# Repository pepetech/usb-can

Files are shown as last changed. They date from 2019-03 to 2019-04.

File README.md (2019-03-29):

# usb-can

This is an open source C++ library for use with the <a href="https://media.giphy.com/media/J0WeVOLjuqW2I/giphy.gif">USB-CAN</a> converter developed by Rafael Silva and João Silva

## Getting Started

These instructions will get you a copy of the project up and running on your local machine for development and testing purposes.

### Prerequisites

- You will need root access to a Linux machine.
- You will need to install development packages for libudev and libusb

- You will need the <a href="https://github.com/signal11/hidapi">hidapi</a> library installed 

- You will need to install libusb
```
sudo apt-get install libudev-dev libusb-1.0-0-dev
```

### Installing

A step by step series of examples that tell you how to get a development environment running

- Clone this repository to your working directory

```
sudo git clone https://github.com/Crying-Face-Emoji/MCP2210-CAN-sdk
```

- Go to the source directory

```
cd MCP2210-CAN-sdk/
```

- Run make

```
sudo make
```

## Running

- You may need to add the provided udev rules to the /etc/udev/rules.d directory.

```
sudo cp mcp2210-hid.rules /etc/udev/rules.d
```
- Depending on your user permissions, you might need to run the compilled binary with root access (sudo)

TODO: Explain how to run the automated tests for this system

## Authors

* **Rafael Silva** - *Initial work* - [crying-face-emoji](https://github.com/crying-face-emoji)
* **João Silva** - *Initial work* - [vankxr](https://github.com/vankxr)

See also the list of [contributors](https://github.com/Crying-Face-Emoji/MCP2210-CAN-sdk/graphs/contributors) who participated in this project.

## License

This project is licensed under the GNU General Public License v3.0 - see the [LICENSE.md](LICENSE.md) file for details

## Acknowledgments

* <a href="https://github.com/kerrydwong/MCP2210-Library">kerrydwong</a> - *mcp2210 library used as base*
* <a href="https://github.com/signal11/hidapi">signal11</a> - *original HID API*

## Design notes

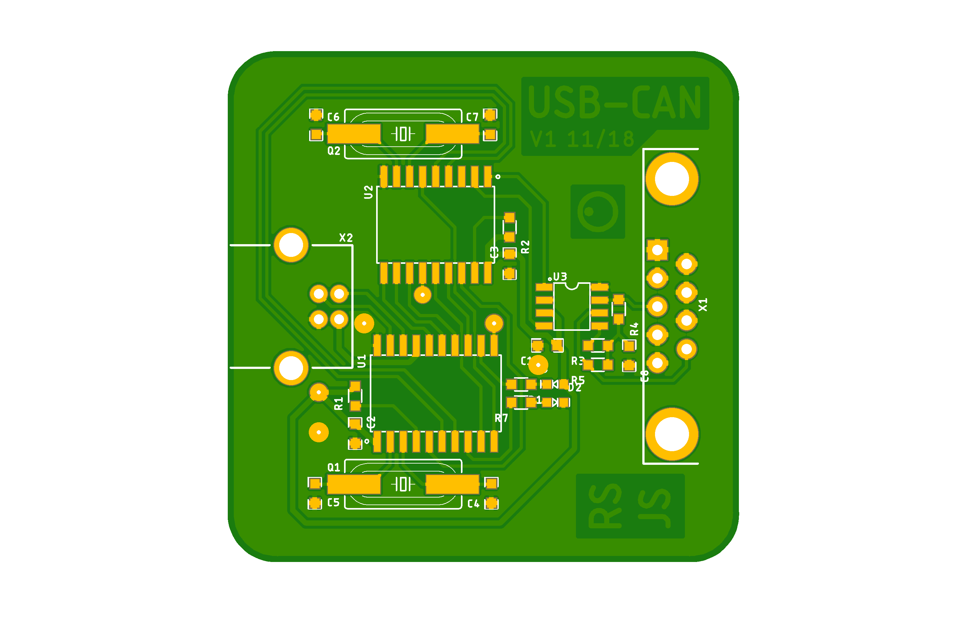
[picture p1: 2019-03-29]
hardware/hv0a/usb-can.png

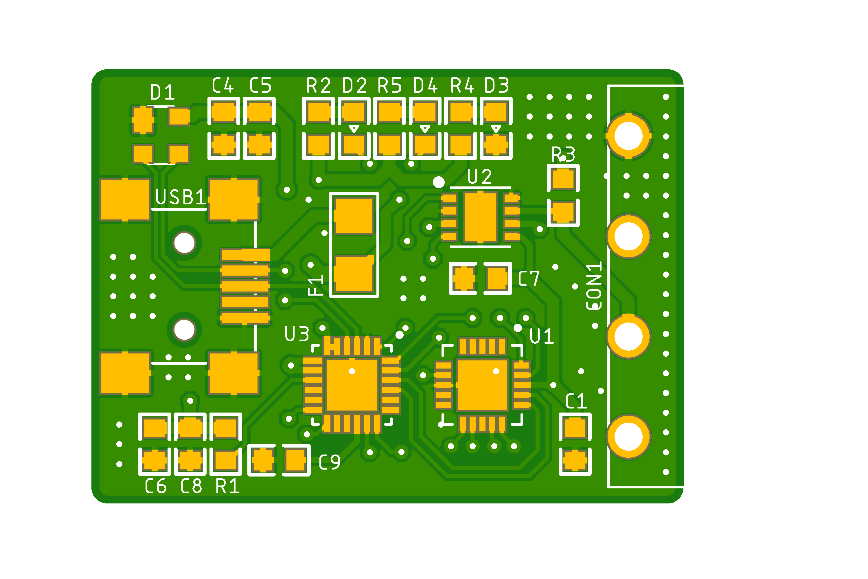
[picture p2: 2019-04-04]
hardware/hv1a/usb-can-top.png

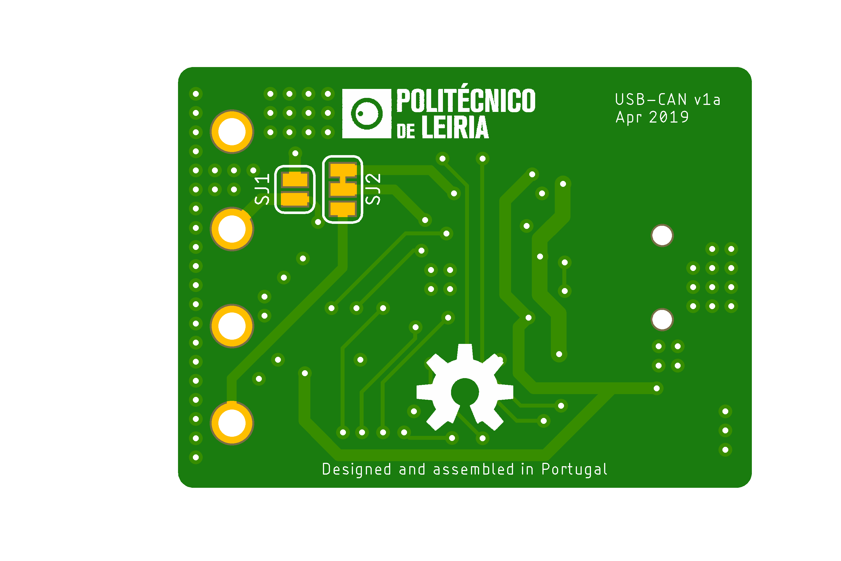
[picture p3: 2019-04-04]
hardware/hv1a/usb-can-bot.png

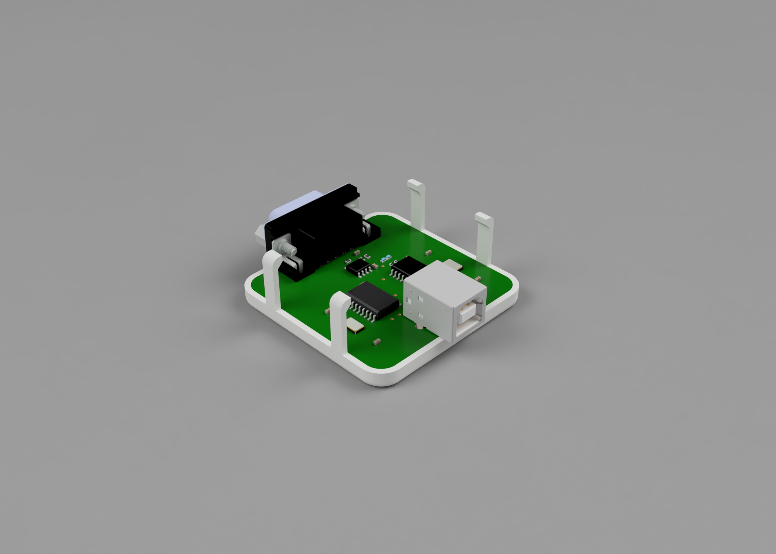
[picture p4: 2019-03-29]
cad/hv0a/asm_2018-Nov-21_03-18-42AM-000_CustomizedView5582314474.png

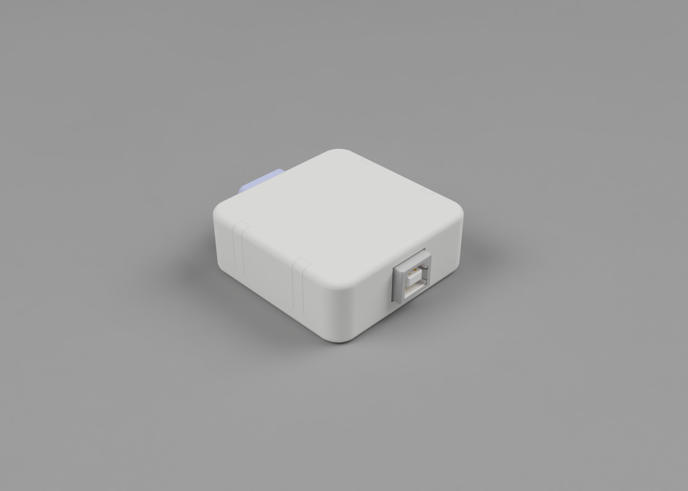
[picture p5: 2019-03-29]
cad/hv0a/asm_2018-Nov-21_03-18-42AM-000_CustomizedView5582314472.png

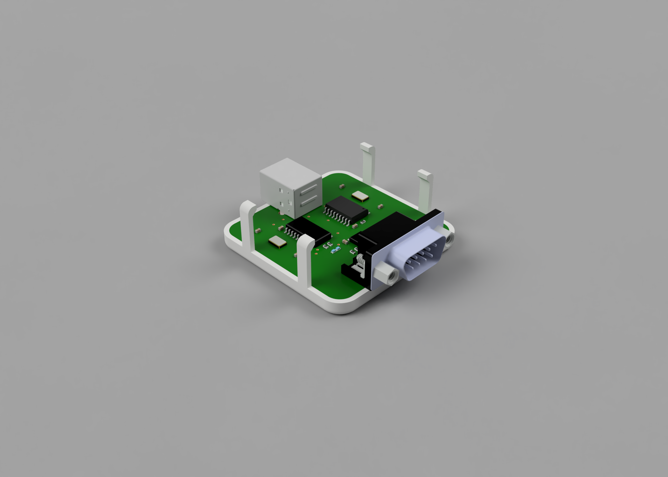
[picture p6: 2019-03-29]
cad/hv0a/asm_2018-Nov-21_03-19-44AM-000_CustomizedView13928471128.png

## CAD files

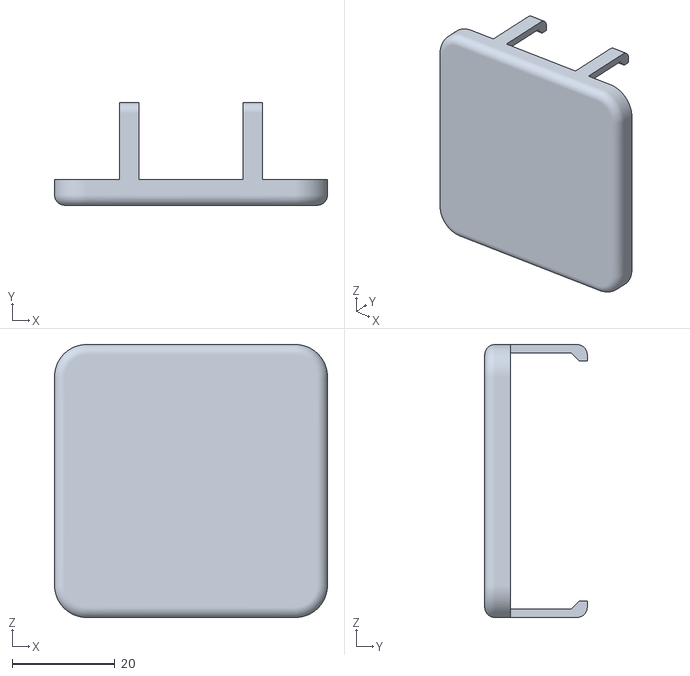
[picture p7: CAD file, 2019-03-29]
cad/hv0a/Bot.stl
53.2 x 20.0 x 53.2

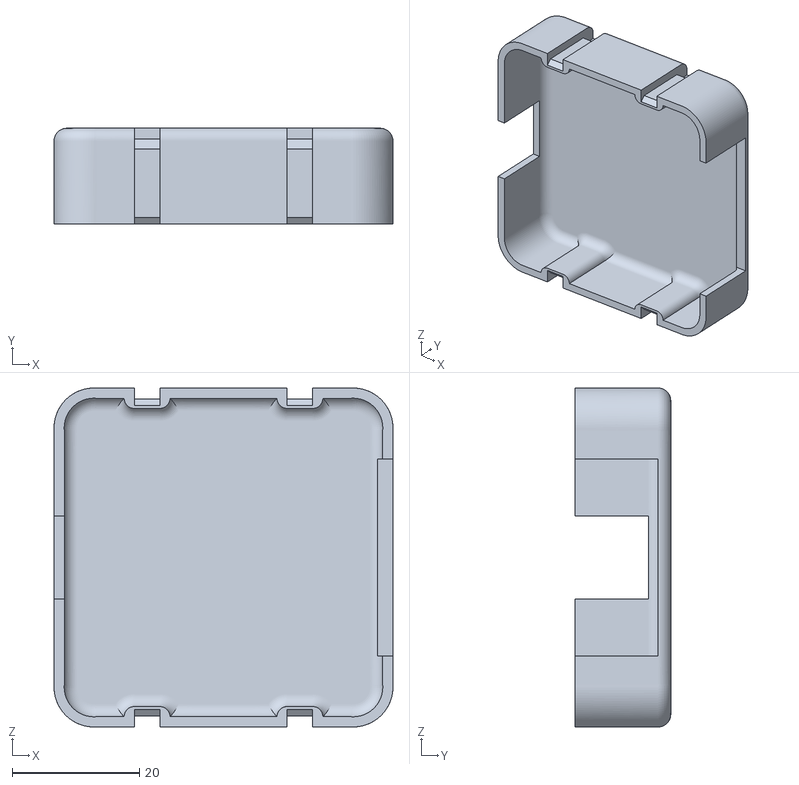
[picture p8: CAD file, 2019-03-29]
cad/hv0a/Top.stl
53.2 x 15.0 x 53.2

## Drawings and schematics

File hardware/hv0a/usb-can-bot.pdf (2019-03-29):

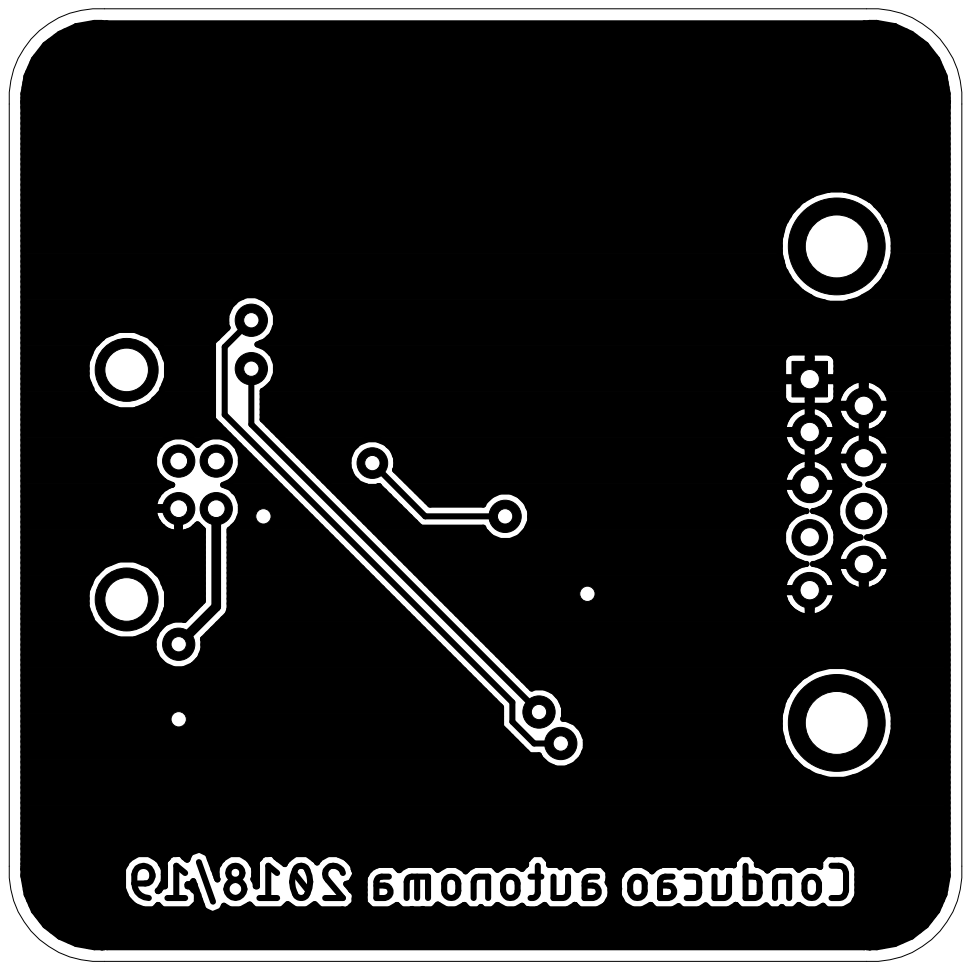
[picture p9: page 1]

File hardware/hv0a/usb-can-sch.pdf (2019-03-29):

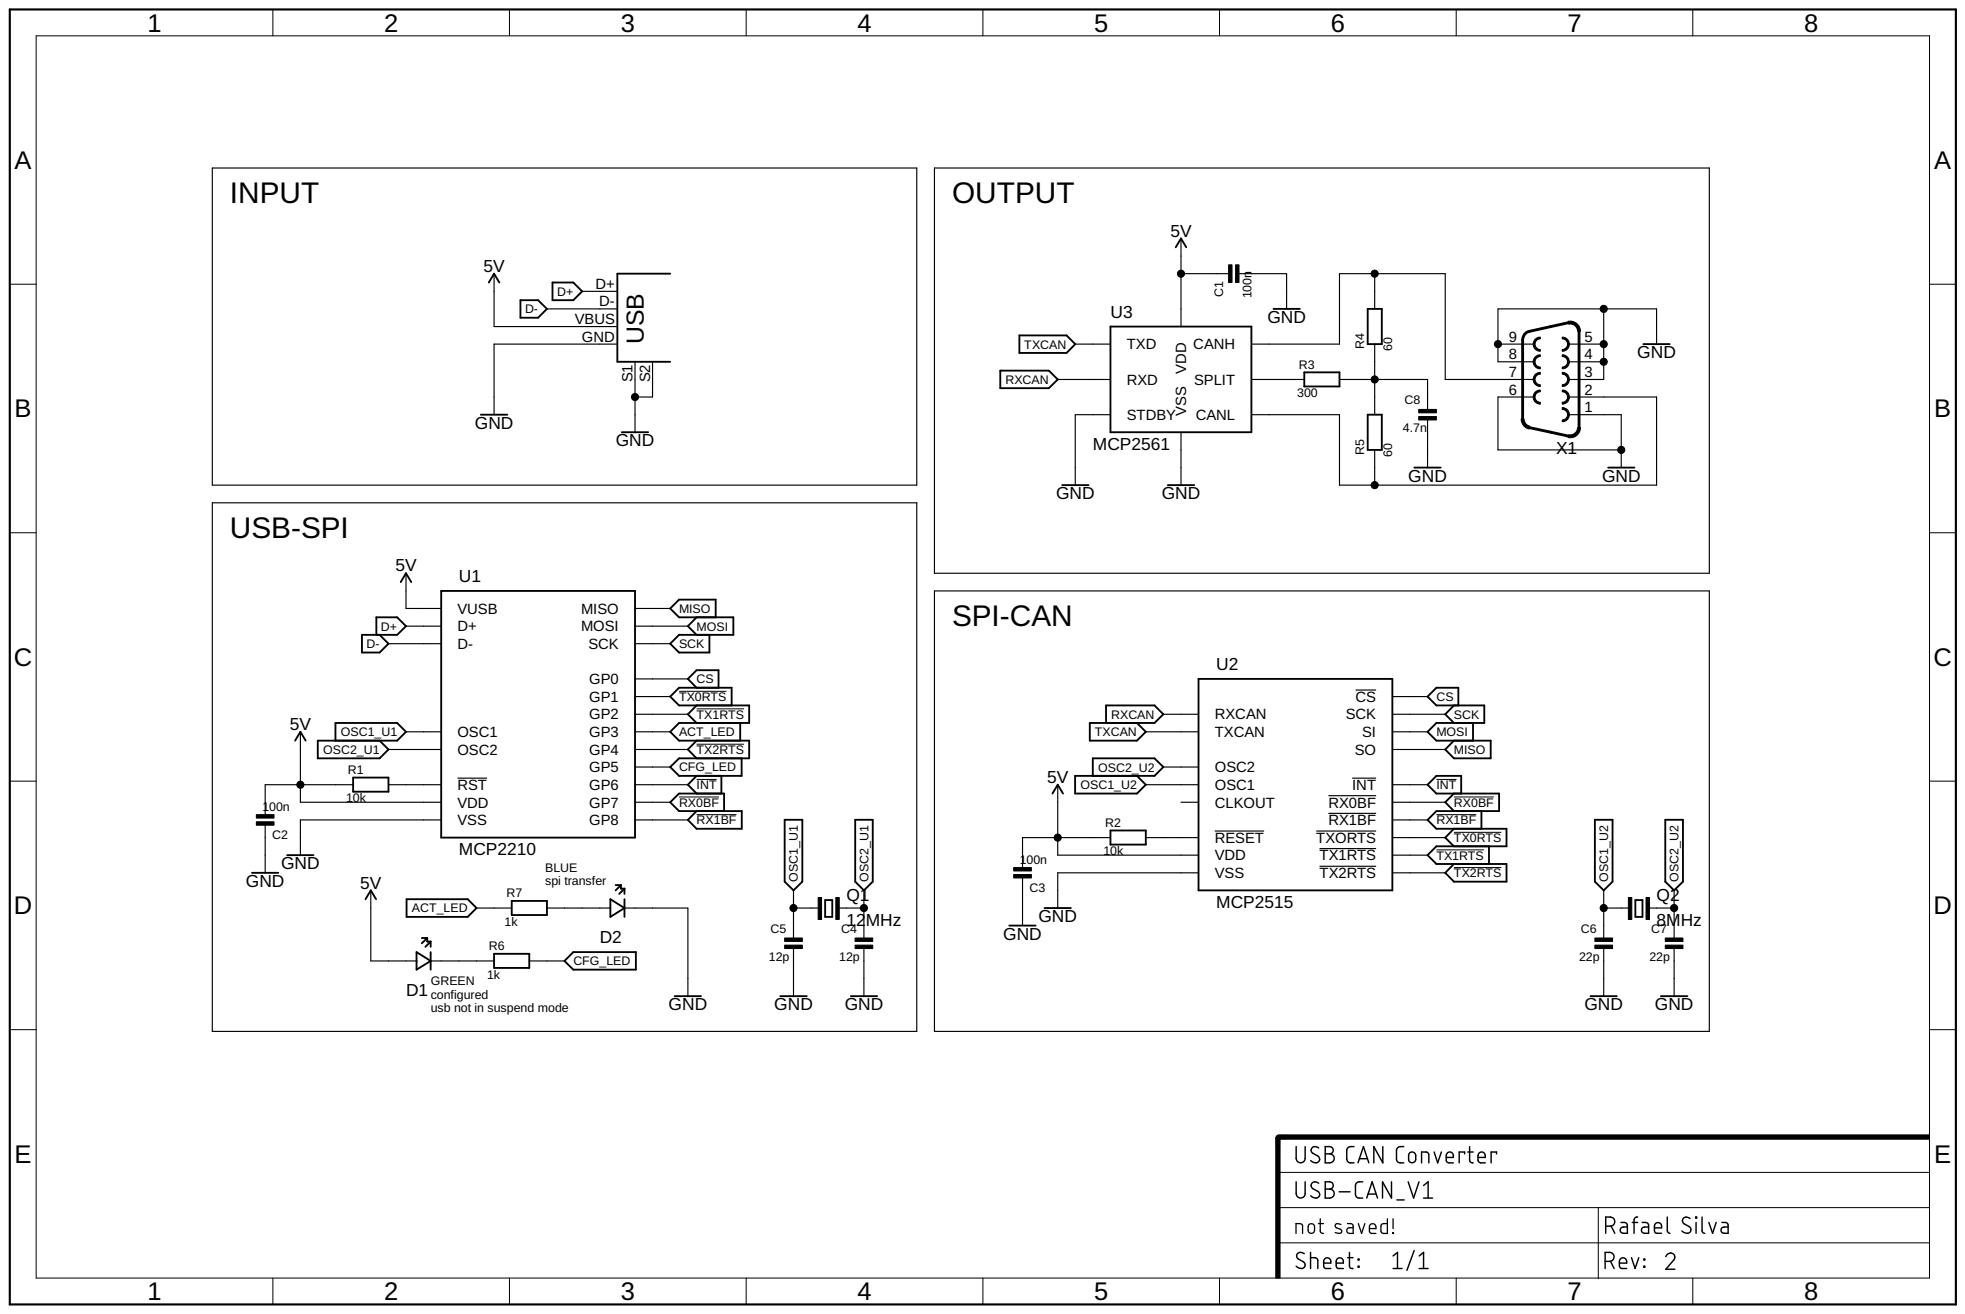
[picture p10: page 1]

GREEN
configured
usb not in suspend mode

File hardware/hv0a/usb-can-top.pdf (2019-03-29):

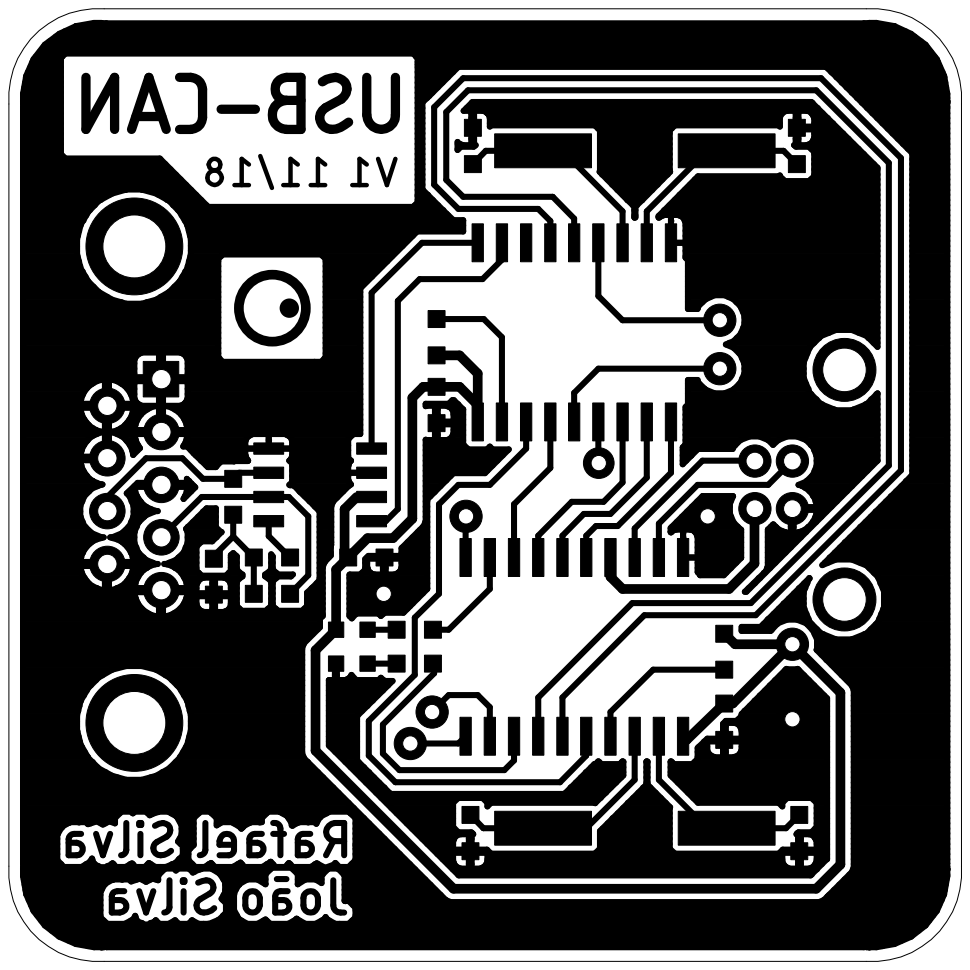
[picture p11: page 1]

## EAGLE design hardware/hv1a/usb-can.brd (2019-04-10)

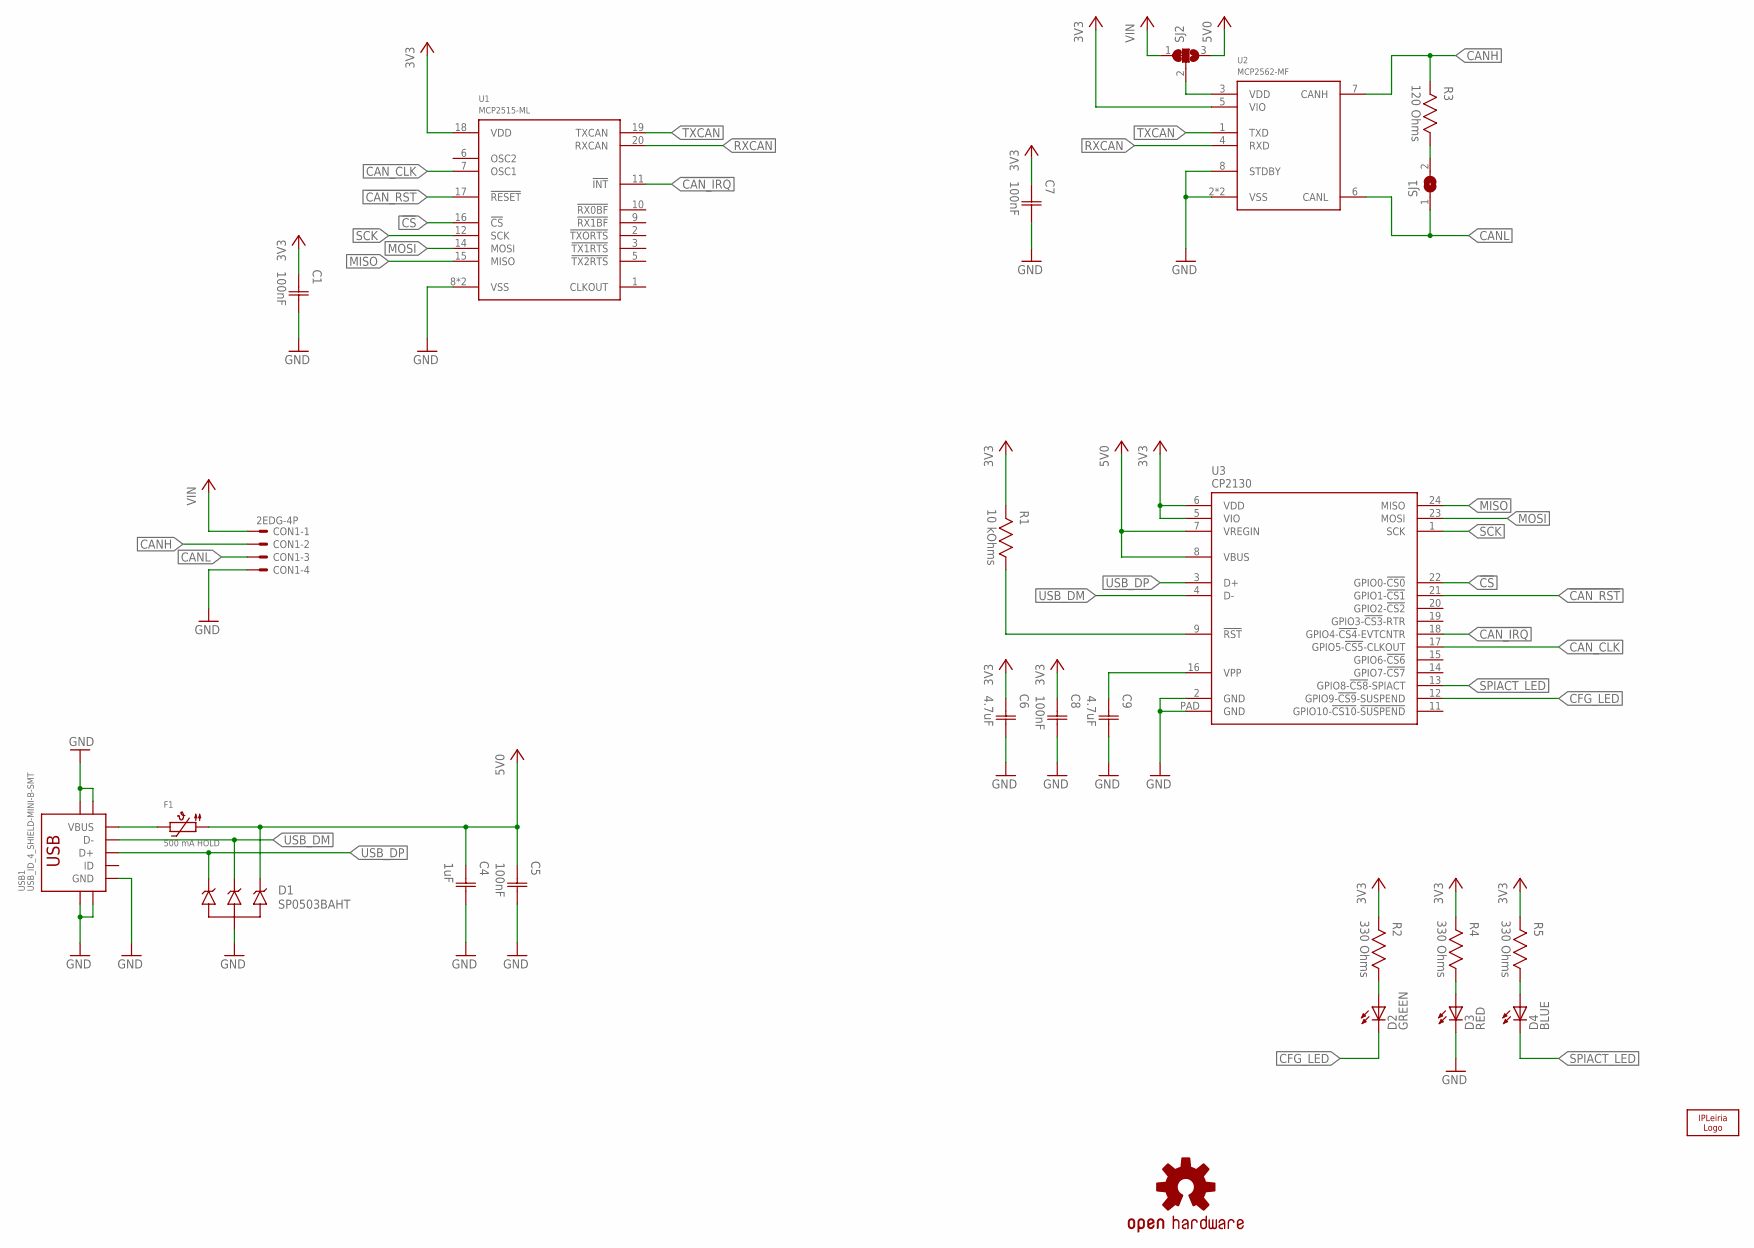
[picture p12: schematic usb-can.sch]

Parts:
C1, C5, C7, C8: 100nF; CAP0603
C4: 1uF; CAP0603
C6, C9: 4.7uF; CAP0603
CON1: 2EDG-4P
D1: SP0503BAHT; SOT143
D2: GREEN; 0603
D3: RED; 0603
D4: BLUE; 0603
F1: 500 mA HOLD; 1206
LOGO1: IPL-10MM; IPL_10MM
LOGO2: OSHW-LOGOM; OSHW-LOGO-M
R1: 10 kOhms; RES0603
R2, R4, R5: 330 Ohms; RES0603
R3: 120 Ohms; RES0603
SJ1: SJS; SJ_S
SJ2: SJ2CS; SJ2C_S
U1: MCP2515-ML; QFN20
U2: MCP2562-MF; DFN8
U3: CP2130; QFN24
USB1: USB_ID_4_SHIELD-MINI-B-SMT; USB-MB-S

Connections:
3V3: C1.1 (C1), C6.1 (C1), C7.1 (C1), C8.1 (C1), R1.2, R2.2, R4.2, R5.2, U1.18 (VDD), U2.5 (VIO), U3.5 (VIO), U3.6 (VDD)
5V0: C4.1 (C1), C5.1 (C1), D1.4, F1.1, SJ2.3, U3.7 (VREGIN), U3.8 (VBUS)
!CAN_IRQ: U1.11 (!INT!), U3.18 (GPIO4-!CS4!-EVTCNTR)
!CAN_RST: U1.17 (!RESET!), U3.21 (GPIO1-!CS1)
!CS: U1.16 (!CS!), U3.22 (GPIO0-!CS0)
CANH: CON1.P$2, R3.2, U2.7 (CANH)
CANL: CON1.P$3, SJ1.1, U2.6 (CANL)
CAN_CLK: U1.7 (OSC1), U3.17 (GPIO5-!CS5!-CLKOUT)
CFG_LED: D2.1 (C), U3.12 (GPIO9-!CS9!-SUSPEND)
GND: C1.2 (C2), C4.2 (C2), C5.2 (C2), C6.2 (C2), C7.2 (C2), C8.2 (C2), C9.2 (C2), CON1.P$4, D1.1, D3.1 (C), U1.8 (VSS), U1.PAD (VSS), U2.2 (VSS), U2.8 (STDBY), U2.9 (VSS), U3.2 (GND), U3.PAD (GND), USB1.GND, USB1.GND1 (SHIELD), USB1.GND2 (SHIELD), USB1.GND3 (SHIELD), USB1.GND4 (SHIELD)
MISO: U1.15 (MISO), U3.24 (MISO)
MOSI: U1.14 (MOSI), U3.23 (MOSI)
unnamed: SJ2.2, U2.3 (VDD)
unnamed: R3.1, SJ1.2
unnamed: C9.1 (C1), U3.16 (VPP)
unnamed: R1.1, U3.9 (!RST)
unnamed: F1.2, USB1.VBUS
unnamed: D3.2 (A), R4.1
unnamed: D4.2 (A), R5.1
unnamed: D2.2 (A), R2.1
RXCAN: U1.20 (RXCAN), U2.4 (RXD)
SCK: U1.12 (SCK), U3.1 (SCK)
SPIACT_LED: D4.1 (C), U3.13 (GPIO8-!CS8!-SPIACT)
TXCAN: U1.19 (TXCAN), U2.1 (TXD)
USB_DM: D1.3, U3.4 (D-), USB1.D-
USB_DP: D1.2, U3.3 (D+), USB1.D+
VIN: CON1.P$1, SJ2.1

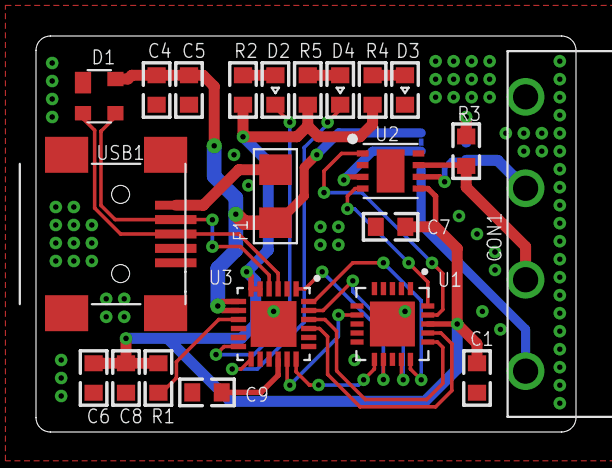
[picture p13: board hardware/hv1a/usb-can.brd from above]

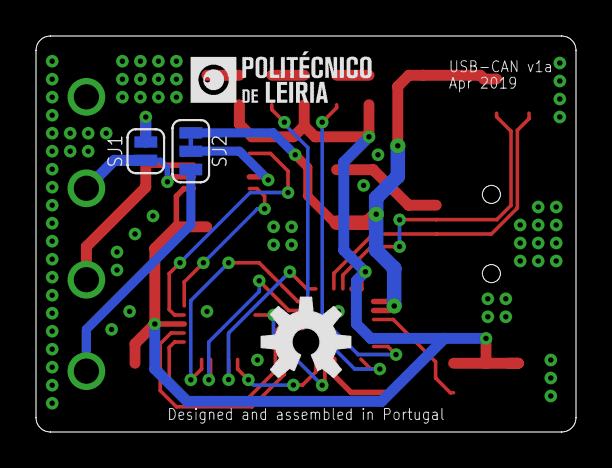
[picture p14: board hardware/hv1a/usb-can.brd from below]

Board: 2 copper layers, 30.0 x 22.0 mm, 26 parts (4 on the bottom side), 27 nets.

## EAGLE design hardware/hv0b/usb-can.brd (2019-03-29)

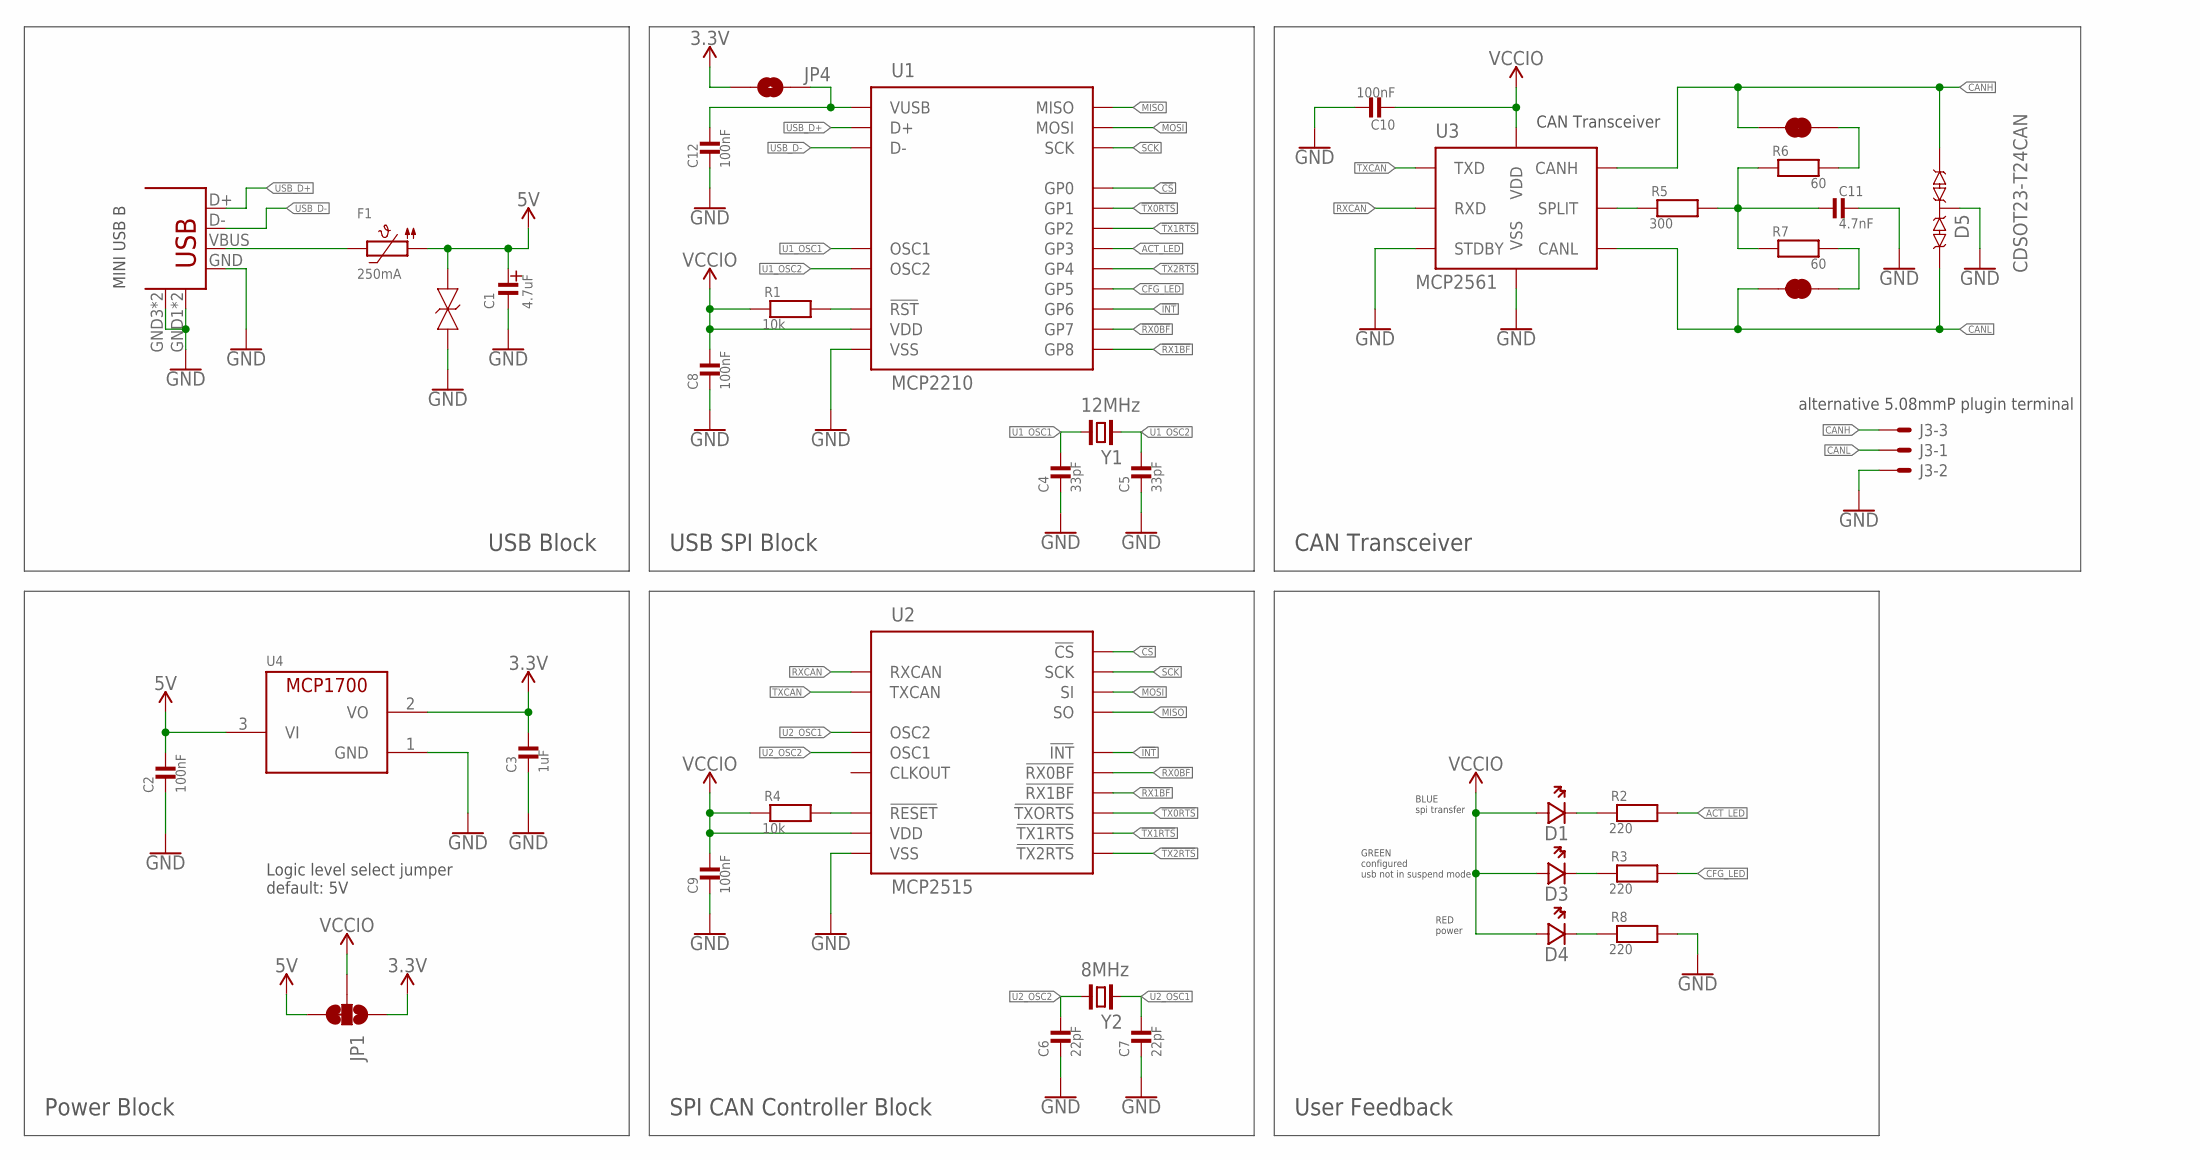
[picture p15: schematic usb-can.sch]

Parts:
C1: 4.7uF; EIA3216
C2, C8, C9, C10, C12: 100nF; 0603_WAVE
C3: 1uF; 0603_WAVE
C4, C5: 33pF; 0603_WAVE
C6, C7: 22pF; 0603_WAVE
C11: 4.7nF; 0603_WAVE
D1: Blue; CHIPLED_0603
D2: PESD5V0S1BAF; SOD323
D3: Green; CHIPLED_0603
D4: Red; CHIPLED_0603
D5: CDSOT23-T24CAN; SOT-23-3
F1: 250mA; _1206
J2: USB_MINI_BMINIB; USB-MINIB
J3: 1X32EHGR; 2EHGR
JP1: JUMPER-SMT_3_1-NC_TRACE_SILK; SMT-JUMPER_3_1-NC_TRACE_SILK
JP2, JP3: JUMPER-SMT_2_NC_TRACE_SILK; SMT-JUMPER_2_NC_TRACE_SILK
JP4: JUMPER-SMT_2_NO_SILK; SMT-JUMPER_2_NO_SILK
R1, R4: 10k; 0603_WAVE
R2, R3, R8: 220; 0603_WAVE
R5: 300; 0603_WAVE
R6, R7: 60; 0603_WAVE
U1: MCP2210; SOIC-20_300MIL
U2: MCP2515; SOIC-18_300MIL
U3: MCP2561; SOIC_8
U4: 250mA; SOT-23
Y1: 12MHz; 2-SMD-5X3
Y2: 8MHz; 2-SMD-5X3

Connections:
3.3V: C3.P$1, JP1.1, JP4.2, U4.2 (VO)
5V: C1.+ (AN), C2.P$1, D2.P$1, F1.1, JP1.3, U4.3 (VI)
!CS: U1.P$5 (GP0), U2.P$16 (!CS!)
!INT: U1.P$14 (GP6), U2.P$12 (!INT!)
!RX0BF: U1.P$15 (GP7), U2.P$11 (!RX0BF!)
!RX1BF: U1.P$16 (GP8), U2.P$10 (!RX1BF!)
!TX0RTS: U1.P$6 (GP1), U2.P$4 (!TXORTS!)
!TX1RTS: U1.P$7 (GP2), U2.P$5 (!TX1RTS!)
!TX2RTS: U1.P$10 (GP4), U2.P$6 (!TX2RTS!)
ACT_LED: R2.P$2, U1.P$8 (GP3)
CANH: D5.P$2 (2), J3.P$3, JP3.2, U3.P$7 (CANH)
CANL: D5.P$1 (1), J3.P$1, JP2.2, U3.P$6 (CANL)
CFG_LED: R3.P$2, U1.P$12 (GP5)
GND: C1.- (CA), C2.P$2, C3.P$2, C4.P$2, C5.P$2, C6.P$2, C7.P$2, C8.P$2, C9.P$2, C10.P$1, C11.P$1, C12.P$2, D2.P$2, D5.P$3 (3), J2.GND, J2.GND1, J2.GND2, J2.GND3, J2.GND4, J3.P$2, R8.P$2, U1.P$20 (VSS), U2.P$9 (VSS), U3.P$2 (VSS), U3.P$8 (STDBY), U4.1 (GND)
MISO: U1.P$13 (MISO), U2.P$15 (SO)
MOSI: U1.P$9 (MOSI), U2.P$14 (SI)
unnamed: JP2.1, R7.P$2
unnamed: D1.C (CA), R2.P$1
unnamed: D3.C (CA), R3.P$1
unnamed: R1.P$2, U1.P$4 (!RST!)
unnamed: R4.P$2, U2.P$17 (!RESET!)
unnamed: D4.C (CA), R8.P$1
unnamed: JP3.1, R6.P$2
unnamed: F1.2, J2.VBUS
unnamed: C12.P$1, JP4.1, U1.P$17 (VUSB)
unnamed: C11.P$2, R5.P$2, R6.P$1, R7.P$1
unnamed: R5.P$1, U3.P$5 (SPLIT)
RXCAN: U2.P$2 (RXCAN), U3.P$4 (RXD)
SCK: U1.P$11 (SCK), U2.P$13 (SCK)
TXCAN: U2.P$1 (TXCAN), U3.P$1 (TXD)
U1_OSC1: C4.P$1, U1.P$2 (OSC1), Y1.1
U1_OSC2: C5.P$1, U1.P$3 (OSC2), Y1.2
U2_OSC1: C7.P$1, U2.P$7 (OSC2), Y2.2
U2_OSC2: C6.P$1, U2.P$8 (OSC1), Y2.1
USB_D+: J2.D+, U1.P$19 (D+)
USB_D-: J2.D-, U1.P$18 (D-)
VCCIO: C8.P$1, C9.P$1, C10.P$2, D1.A (AN), D3.A (AN), D4.A (AN), JP1.2, R1.P$1, R4.P$1, U1.P$1 (VDD), U2.P$18 (VDD), U3.P$3 (VDD)

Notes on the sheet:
BLUE spi transfer
GREEN configured usb not in suspend mode
RED power
alternative 5.08mmP plugin terminal
CAN Transceiver
MINI USB B
Logic level select jumper default: 5V
Power Block
USB Block
USB SPI Block
SPI CAN Controller Block
User Feedback

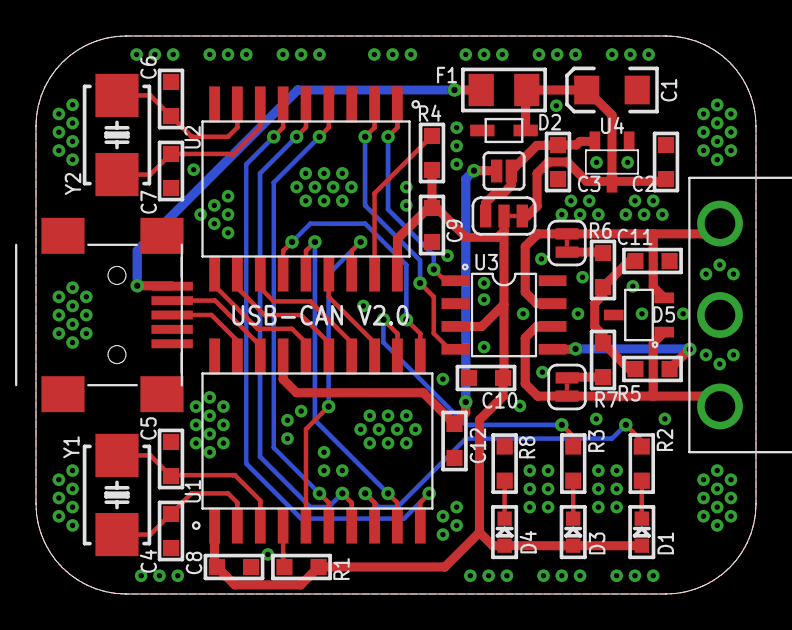
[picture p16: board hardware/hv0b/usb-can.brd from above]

Board: 2 copper layers, 40.0 x 31.0 mm, 38 parts (0 on the bottom side), 37 nets.

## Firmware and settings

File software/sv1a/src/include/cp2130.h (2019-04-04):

#ifndef __CP2130_H
#define __CP2130_H

#include <libusb-1.0/libusb.h>
#include <string.h>
#include <uchar.h>
#include <stdio.h>
#include <stdlib.h>
#include <unistd.h>

// OTP ROM WRITE PROTECT
#define CP2130_OTP_ROM_WRITE_PROTECT

// Product and vendor ids
#define CP2130_VID  0x10C4
#define CP2130_PID  0x87A0

// EndPoints
#define CP2130_EP_HOST_DEVICE   0x01
#define CP2130_EP_DEVICE_HOST   0x82

// Request types
#define CP2130_REQ_DEVICE_HOST_VENDOR   0xC0
#define CP2130_REQ_HOST_DEVICE_VENDOR   0x40

// memory Key
#define CP2130_MEM_KEY  0xA5F1

// Command ID's
// Data Transfer Commands (Bulk Transfers)
#define CP2130_CMDID_READ           0x00
#define CP2130_CMDID_WRITE          0x01
#define CP2130_CMDID_WRITEREAD      0x02
#define CP2130_CMDID_READRTR        0x04
// Configuration and Control Commands (Control Transfers)
#define CP2130_CMDID_GET_CLK_DIV    0x46
#define CP2130_CMDID_SET_CLK_DIV    0x47
#define CP2130_CMDID_GET_EVNT_CNT   0x44
#define CP2130_CMDID_SET_EVNT_CNT   0x45
#define CP2130_CMDID_GET_FULL_TH    0x34
#define CP2130_CMDID_SET_FULL_TH    0x35
#define CP2130_CMDID_GET_GPIO_CS    0x24
#define CP2130_CMDID_SET_GPIO_CS    0x25
#define CP2130_CMDID_GET_GPIO_MDLVL 0x22
#define CP2130_CMDID_SET_GPIO_MDLVL 0x23
#define CP2130_CMDID_GET_GPIO_VAL   0x20
#define CP2130_CMDID_SET_GPIO_VAL   0x21
#define CP2130_CMDID_GET_RTR_STATE  0x36
#define CP2130_CMDID_RTR_STOP       0x37
#define CP2130_CMDID_GET_SPI_WORD   0x30
#define CP2130_CMDID_SET_SPI_WORD   0x31
#define CP2130_CMDID_GET_SPI_DELAY  0x32
#define CP2130_CMDID_SET_SPI_DELAY  0x33
#define CP2130_CMDID_GET_VERSION    0x11
#define CP2130_CMDID_RESET          0x10
// OTP ROM Configuration Commands (Control Transfers)
#define CP2130_CMDID_GET_LOCK_BYTE  0x6E
#define CP2130_CMDID_SET_LOCK_BYTE  0x6F
#define CP2130_CMDID_GET_MAN_STR_1  0x62
#define CP2130_CMDID_SET_MAN_STR_1  0x63
#define CP2130_CMDID_GET_MAN_STR_2  0x64
#define CP2130_CMDID_SET_MAN_STR_2  0x65
#define CP2130_CMDID_GET_PIN_CFG    0x6C
#define CP2130_CMDID_SET_PIN_CFG    0x6D
#define CP2130_CMDID_GET_PROD_STR_1 0x66
#define CP2130_CMDID_SET_PROD_STR_1 0x63
#define CP2130_CMDID_GET_PROD_STR_2 0x68
#define CP2130_CMDID_SET_PROD_STR_2 0x69
#define CP2130_CMDID_GET_PROM_CFG   0x70
#define CP2130_CMDID_SET_PROM_CFG   0x71
#define CP2130_CMDID_GET_SERIAL_STR 0x6A
#define CP2130_CMDID_SET_SERIAL_STR 0x6B
#define CP2130_CMDID_GET_USB_CFG    0x60
#define CP2130_CMDID_SET_USB_CFG    0x61

// Event Counter
#define CP2130_EVNT_CNT_OF_FLAG     0x80
#define CP2130_EVNT_CNT_RISING_EDG  0x02
#define CP2130_EVNT_CNT_FALLING_EDG 0x03
#define CP2130_EVNT_CNT_NEG_PULSE   0x06
#define CP2130_EVNT_CNT_POS_PULSE   0x07

// GPIO CS
#define CP2130_CS_CH0   0
#define CP2130_CS_CH1   1
#define CP2130_CS_CH2   2
#define CP2130_CS_CH3   3
#define CP2130_CS_CH4   4
#define CP2130_CS_CH5   5
#define CP2130_CS_CH6   6
#define CP2130_CS_CH7   7
#define CP2130_CS_CH8   8
#define CP2130_CS_CH9   9
#define CP2130_CS_CH10  10

#define CP2130_CS_MD_DIS    0x00
#define CP2130_CS_MD_EN     0x01
#define CP2130_CS_MD_EN_DIS_OTHERS 0x02

#define CP2130_CS_EN_MSK_CH0    0x0001
#define CP2130_CS_EN_MSK_CH1    0x0002
#define CP2130_CS_EN_MSK_CH2    0x0004
#define CP2130_CS_EN_MSK_CH3    0x0008
#define CP2130_CS_EN_MSK_CH4    0x0010
#define CP2130_CS_EN_MSK_CH5    0x0020
#define CP2130_CS_EN_MSK_CH6    0x0040
#define CP2130_CS_EN_MSK_CH7    0x0080
#define CP2130_CS_EN_MSK_CH8    0x0100
#define CP2130_CS_EN_MSK_CH9    0x0200
#define CP2130_CS_EN_MSK_CH10   0x0400

#define CP2130_CS_PIN_EN_MSK_CH0    0x0008
#define CP2130_CS_PIN_EN_MSK_CH1    0x0010
#define CP2130_CS_PIN_EN_MSK_CH2    0x0020
#define CP2130_CS_PIN_EN_MSK_CH3    0x0040
#define CP2130_CS_PIN_EN_MSK_CH4    0x0080
#define CP2130_CS_PIN_EN_MSK_CH5    0x0100
#define CP2130_CS_PIN_EN_MSK_CH6    0x0400
#define CP2130_CS_PIN_EN_MSK_CH7    0x0800
#define CP2130_CS_PIN_EN_MSK_CH8    0x1000
#define CP2130_CS_PIN_EN_MSK_CH9    0x2000
#define CP2130_CS_PIN_EN_MSK_CH10   0x4000

// GPIO mask mode level and value
#define CP2130_GPIO0_MSK    0x0008
#define CP2130_GPIO1_MSK    0x0010
#define CP2130_GPIO2_MSK    0x0020
#define CP2130_GPIO3_MSK    0x0040
#define CP2130_GPIO4_MSK    0x0080
#define CP2130_GPIO5_MSK    0x0100
#define CP2130_GPIO6_MSK    0x0400
#define CP2130_GPIO7_MSK    0x0800
#define CP2130_GPIO8_MSK    0x1000
#define CP2130_GPIO9_MSK    0x2000
#define CP2130_GPIO10_MSK   0x4000

#define CP2130_GPIO0    0
#define CP2130_GPIO1    1
#define CP2130_GPIO2    2
#define CP2130_GPIO3    3
#define CP2130_GPIO4    4
#define CP2130_GPIO5    5
#define CP2130_GPIO6    6
#define CP2130_GPIO7    7
#define CP2130_GPIO8    8
#define CP2130_GPIO9    9
#define CP2130_GPIO10   10

#define CP2130_GPIO_IN      0x00
#define CP2130_GPIO_OUT_OD  0x01
#define CP2130_GPIO_OUT_PP  0x02

#define CP2130_GPIO_LOW     0x00
#define CP2130_GPIO_HIGH    0x01

// RTR
#define CP2130_ABORT_READRTR    0x01

// SPI word
#define CP2130_SPI_WRD_CLK_LEAD             0x00
#define CP2130_SPI_WRD_CLK_TRAIL            0x20
#define CP2130_SPI_WRD_CLK_POL_IDLE_LOW     0x00
#define CP2130_SPI_WRD_CLK_POL_IDLE_HIGH    0x10
#define CP2130_SPI_WRD_CS_MODE_OD           0x00
#define CP2130_SPI_WRD_CS_MODE_PP           0x08
#define CP2130_SPI_WRD_CLK_12M              0x00
#define CP2130_SPI_WRD_CLK_6M               0x01
#define CP2130_SPI_WRD_CLK_3M               0x02
#define CP2130_SPI_WRD_CLK_1_5M             0x03
#define CP2130_SPI_WRD_CLK_750K             0x04
#define CP2130_SPI_WRD_CLK_375K             0x05
#define CP2130_SPI_WRD_CLK_187_5K           0x06
#define CP2130_SPI_WRD_CLK_93_8K            0x07

#define CP2130_SPI_CH0   0
#define CP2130_SPI_CH1   1
#define CP2130_SPI_CH2   2
#define CP2130_SPI_CH3   3
#define CP2130_SPI_CH4   4
#define CP2130_SPI_CH5   5
#define CP2130_SPI_CH6   6
#define CP2130_SPI_CH7   7
#define CP2130_SPI_CH8   8
#define CP2130_SPI_CH9   9
#define CP2130_SPI_CH10  10

// Lock Byte
#define CP2130_LOCK_PROD_STR1   0x0001
#define CP2130_LOCK_PROD_STR2   0x0002
#define CP2130_LOCK_SERIAL_STR1 0x0004
#define CP2130_LOCK_PIN_CFG     0x0008
#define CP2130_LOCK_VID         0x0100
#define CP2130_LOCK_PID         0x0200
#define CP2130_LOCK_MAX_POW     0x0400
#define CP2130_LOCK_POW_MODE    0x0800
#define CP2130_LOCK_RELEASE_VER 0x1000
#define CP2130_LOCK_MAN_STR2    0x2000
#define CP2130_LOCK_MAN_STR1    0x4000
#define CP2130_LOCK_TRANS_PRTY  0x8000

// SPI delay
#define CP2130_SPI_DELAY_MSK

// USB Config
#define CP2130_USP_MAX_POW_MA(ma)       ((uint8_t)(ma / 2u))
#define CP2130_USB_BUS_POW_REG_EN       0x00
#define CP2130_USB_SELF_POW_REG_DIS     0x01
#define CP2130_USB_SELF_POW_REG_EN      0x02
#define CP2130_USB_PRIORITY_WRITE       0x01
#define CP2130_USB_PRIORITY_READ        0x00
#define CP2130_USB_CFG_MSK_VID          0x01
#define CP2130_USB_CFG_MSK_PID          0x02
#define CP2130_USB_CFG_MSK_MAX_POW      0x04
#define CP2130_USB_CFG_MSK_POW_MODE     0x08
#define CP2130_USB_CFG_MSK_VERSION      0x10
#define CP2130_USB_CFG_MSK_PRIORITY     0x80
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

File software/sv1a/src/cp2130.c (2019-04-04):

// SiLabs CP2130 via LibUSB

#include "cp2130.h"

#ifdef __cplusplus
extern "C" {
#endif

cp2130_device_t *cp2130_init(libusb_context *ctx)
{
    printf("allocating space for cp2130 device...\r\n");
    cp2130_device_t *pCp2130_dev = (cp2130_device_t *)malloc(sizeof(cp2130_device_t));
    if(!pCp2130_dev)
    {
        printf("ERROR: cp2130 device space allocation failed.\r\n");
        return NULL;
    }

    pCp2130_dev->pDev = NULL;
    pCp2130_dev->ubKernelAttached = 0;
    pCp2130_dev->usTimeout = 0;

    printf("opening cp2130 device...\r\n");
    pCp2130_dev->pDev = libusb_open_device_with_vid_pid(ctx, CP2130_VID, CP2130_PID);
    if(pCp2130_dev->pDev == NULL)
    {
        printf("ERROR: libusb could not open cp2130 device.\r\n");
        free(pCp2130_dev);
        return NULL;
    }

    printf("cp2130 detaching from kernel if attached...\r\n");
    if(libusb_kernel_driver_active(pCp2130_dev->pDev, 0) != 0)
    {
        printf("cp2130 device was atached to kernel, detaching...\r\n");
        libusb_detach_kernel_driver(pCp2130_dev->pDev, 0);
        pCp2130_dev->ubKernelAttached = 1;
    }

    printf("cp2130 device claiming interface...\r\n");
    if(libusb_claim_interface(pCp2130_dev->pDev, 0) < 0)
    {
        printf("ERROR: could not claim interface.\r\n");
        if(pCp2130_dev->ubKernelAttached)
            libusb_attach_kernel_driver(pCp2130_dev->pDev, 0);

        libusb_close(pCp2130_dev->pDev);
        free(pCp2130_dev);
        return NULL;
    }

    printf("cp2130 initialization success...\r\n");
    return pCp2130_dev;
}
void cp2130_free(cp2130_device_t *pCpDev)
{
    if(!pCpDev)
        return;

    libusb_release_interface(pCpDev->pDev, 0);

    if(pCpDev->ubKernelAttached)
        libusb_attach_kernel_driver(pCpDev->pDev, 0);

    libusb_close(pCpDev->pDev);

    free(pCpDev);
}

static void cp2130_control_transfer(cp2130_device_t *pCpDev, uint8_t ubReqType, uint8_t ubRequest, uint8_t * pubData, uint16_t usLen, uint16_t usWvalue, uint16_t usWindex)
{
    int32_t ulR = libusb_control_transfer(pCpDev->pDev, ubReqType, ubRequest, usWvalue, usWindex, pubData, usLen, pCpDev->usTimeout);
    if(ulR < 0)
        printf("control_transfer failed with return code %d\r\n", ulR);
}
static void cp2130_bulk_transfer(cp2130_device_t *pCpDev, uint8_t ubEp, uint8_t * pubData, uint32_t ulLen)
{
    uint32_t ulTransferred;
    uint32_t ulR = libusb_bulk_transfer(pCpDev->pDev, ubEp, pubData, ulLen, (int *)(&ulTransferred), pCpDev->usTimeout);
    if(ulR < 0)
        printf("bulk_transfer failed with return code %d\r\n", ulR);

    if(ulTransferred < ulLen)
        printf("bulk_transfer failed short: %d bytes of %d requested\r\n", ulTransferred, ulLen);
}

// Data Transfer Commands (Bulk Transfers)
void cp2130_spi_transfer(cp2130_device_t *pCpDev, uint8_t *pubData, uint32_t ulLen)
{
    if (ulLen > 120)
    {
        printf("cannot send more than 120 bytes in transfer, use write or read\r\n");
        return;
    }

    uint8_t *pubCmdBuf = (uint8_t *)malloc(MIN(ulLen + 8, 64u));
    memset(pubCmdBuf, 0x00, MIN(ulLen + 8, 64u));

	pubCmdBuf[0] = 0x00;  // reserved must be 0x00
    pubCmdBuf[1] = 0x00;  // reserved must be 0x00
    pubCmdBuf[2] = CP2130_CMDID_WRITEREAD;  // Command ID
    pubCmdBuf[3] = 0x00;  // reserved
    //pubDataBuf[7] = (uint8_t)((ulLen >> 24) & 0xFF); pubDataBuf[6] = (uint8_t)((ulLen >> 16) & 0xFF); pubDataBuf[5] = (uint8_t)((ulLen >> 8) & 0xFF);  // Length
    pubCmdBuf[4] = (uint8_t)(ulLen & 0xFF);  // Length Little Endian (since max is 120 we only need this)

    memcpy((pubCmdBuf + 8u), pubData, MIN(ulLen, 56u));

	cp2130_bulk_transfer(pCpDev, CP2130_EP_HOST_DEVICE, pubCmdBuf, MIN(ulLen + 8u, 64u));
	cp2130_bulk_transfer(pCpDev, CP2130_EP_DEVICE_HOST, pubData, MIN(ulLen, 56u));

    for(uint32_t ulTransfered = 56; ulTransfered < ulLen; ulTransfered += 64u)
    {
        uint32_t ulToTransfer = MIN(ulLen - ulTransfered, 64u);
        cp2130_bulk_transfer(pCpDev, CP2130_EP_HOST_DEVICE, pubData + ulTransfered, ulToTransfer);
		cp2130_bulk_transfer(pCpDev, CP2130_EP_DEVICE_HOST, pubData + ulTransfered, ulToTransfer);
    }
}
void cp2130_spi_write(cp2130_device_t *pCpDev, uint8_t *pubData, uint32_t ulLen)
{
    uint8_t *pubCmdBuf = (uint8_t *)malloc(MIN(ulLen + 8, 64u));
    memset(pubCmdBuf, 0x00, MIN(ulLen + 8, 64u));

	pubCmdBuf[0] = 0x00;  // reserved must be 0x00
    pubCmdBuf[1] = 0x00;  // reserved must be 0x00
    pubCmdBuf[2] = CP2130_CMDID_WRITE;  // Command ID
    pubCmdBuf[3] = 0x00;  // reserved
    pubCmdBuf[7] = (uint8_t)((ulLen >> 24) & 0xFF);    // Length
    pubCmdBuf[6] = (uint8_t)((ulLen >> 16) & 0xFF);    // Length
    pubCmdBuf[5] = (uint8_t)((ulLen >> 8) & 0xFF);     // Length
    pubCmdBuf[4] = (uint8_t)(ulLen & 0xFF);        // Length Little Endian

    memcpy((pubCmdBuf + 8u), pubData, MIN(ulLen, 56u));

	// send the command and first 56 or fewer bytes
	cp2130_bulk_transfer(pCpDev, CP2130_EP_HOST_DEVICE, pubCmdBuf, MIN(ulLen + 8u, 64u));
	// send the remainder
	uint32_t count = 56;
	for(uint32_t ulTransfered = 56; ulTransfered < ulLen; ulTransfered += 64u)
    {
        cp2130_bulk_transfer(pCpDev, CP2130_EP_HOST_DEVICE, pubData + ulTransfered, MIN(ulLen - ulTransfered, 64u));
    }
}
void cp2130_spi_read(cp2130_device_t *pCpDev, uint8_t *pubData, uint32_t ulLen)
{
    uint8_t *pubCmdBuf = (uint8_t *)malloc(MIN(ulLen + 8, 64u));
    memset(pubCmdBuf, 0x00, MIN(ulLen + 8, 64u));

	pubCmdBuf[0] = 0x00;  // reserved must be 0x00
    pubCmdBuf[1] = 0x00;  // reserved must be 0x00
    pubCmdBuf[2] = CP2130_CMDID_READ;  // Command ID
    pubCmdBuf[3] = 0x00;  // reserved
    pubCmdBuf[7] = (uint8_t)((ulLen >> 24) & 0xFF);    // Length
    pubCmdBuf[6] = (uint8_t)((ulLen >> 16) & 0xFF);    // Length
    pubCmdBuf[5] = (uint8_t)((ulLen >> 8) & 0xFF);     // Length
    pubCmdBuf[4] = (uint8_t)(ulLen & 0xFF);        // Length Little Endian

	cp2130_bulk_transfer(pCpDev, CP2130_EP_HOST_DEVICE, pubCmdBuf, 8u);   // send the command
	// fetch the data
	for(uint32_t ulTransfered = 0; ulTransfered < ulLen; ulTransfered += 64u)
    {
		cp2130_bulk_transfer(pCpDev, CP2130_EP_DEVICE_HOST, pubData + ulTransfered, MIN(ulLen - ulTransfered, 64u));
	}
}
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

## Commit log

2018-11-21 xis de
2018-11-21 xis de dois
2019-02-10 Set SPI clock back to 10 MHz
    Was 1 MHz for testing
2019-03-29 changed project structure, consolidated project files
    [Bot.stl, Top.stl, USB-CAN_V1.brd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]
2019-03-30 Organize and add v1a sch
    [usb-can.brd, usb-can.sch]
2019-04-03 Commit to update
    [usb-can.brd, usb-can.sch]
2019-04-04 Work on PCB
    [usb-can.brd, usb-can.sch]
2019-04-04 Hardware v1a completed
    [usb-can.brd, usb-can.sch]
2019-04-04 Center text
    [usb-can.brd]
2019-04-04 fixed bug in sv0a
    [mcp2210test.cpp]
2019-04-10 Add more vias and generate gerbers
    [usb-can.brd]

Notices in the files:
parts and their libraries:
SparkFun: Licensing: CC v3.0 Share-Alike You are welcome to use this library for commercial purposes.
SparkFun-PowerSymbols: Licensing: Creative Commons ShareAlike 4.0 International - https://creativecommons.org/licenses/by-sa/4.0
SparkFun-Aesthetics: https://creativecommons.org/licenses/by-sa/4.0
